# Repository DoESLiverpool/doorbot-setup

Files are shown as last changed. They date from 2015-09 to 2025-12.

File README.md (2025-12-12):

# Setup Doorbot

A set of scripts to set up a DoESLiverpool DoorBot.

## Structure

DoES Liverpool has three types of doorbot.  Most of the basics are shared between them all, and that is all contained within the `base-doorbot` role.  Other roles, such as the one running a web browser for doorbot1, are layered on top of that.

## Steps:

1. Install [Ansible](https://www.ansible.com/get-started) on your computer
1. Using the [Raspberry Pi Imager](https://www.raspberrypi.com/software/) install the latest 32-bit (I think John had trouble with the RFID code on the 64-bit) OS (needs updating for the headless ones, I used the desktop one as it was `doorbot2` that I was fixing, but I think we'd want "Raspberry Pi OS Lite"), and edit the settings to configure:
   * hostname
   * password
   * SSID
   * WiFi password
   * Enable the ssh service (use password authentication)
   (this didn't actually seem to set any of those options when I just tried it, and I had to do them manually with a screen and keyboard when the Pi first booted up)
1. Boot the Raspberry Pi with the micro-SD card, while plugged into a network via Ethernet
1. Find out the IP address of the Raspberry Pi
 * Use nmap (eg: `nmap -p 22 10.0.*.* --open`), router or monitor to find IP address of Pi once booted.
1. Copy your SSH credentials onto the Pi
  ```ssh-copy-id pi@<ip-address-of-the-pi>```
1. Edit the ```./hosts``` file so ansible knows which computer to configure.  Change the IP address in it to match the one you just found out.
1. Check you can run commands on the Pi using Ansible
   ```ansible <doorbotN> -i hosts -a "hostname" -u pi```
1. Create the hashed password file to use in a moment (if you don't already have it). At the prompt, provide the relevant password for the doorbot
   ```mkpasswd --method=sha-512 > protected_scripts/doorbot1-pwd.txt```
1. Change the SSH port and default password on the doorbot
   ```ansible-playbook ssh-config-doorbot1.yml -e pi_password=`cat protected_scripts/doorbot1-pwd.txt` -i hosts```
1. Populate `protected_scripts/id_ed25519` and `protected_scripts/id_ed25519.pub`, most likely by copying contents from an existing doorbot.
1. Update the Pi, using the correct playbook for the doorbot you're creating, e.g.
   ```ansible-playbook doorbot1.yml -i hosts```

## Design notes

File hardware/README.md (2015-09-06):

# Hardware

The non-software parts of a Doorbot.  

## pi-interface

KiCad project to define the PCB to interface from a Raspberry Pi to the SL030 RFID reader and a 12V door striker solenoid.  Takes power from a standard PC hard drive power connector.

Requires a number of additional parts libraries:

 * https://github.com/KiCad/kicad-library
 * http://www.smisioto.eu/elettronica/kicad

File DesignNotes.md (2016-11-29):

# DoES Liverpool Electronic Locking System

## Live System

There is a system currently live built on Raspberry Pi, this is not the final design but is enough to keep us going. More information on DoorBot page.

## Future Plans

This page contains some information about the electronic locking system for DoES Liverpool. This system is currently in the planning stages.

### Specifications

 * Computer can open door
  * Should fail locked
  * Can be opened by local RFID scan
  * Can be opened by a webpage which requires you to be on the local internet
  * Can be opened by administrators through other methods (SSH, doesbot, etc.)
 * RFID scan works offline (regularly downloads RFID details locally, or they're just stored there anyway)
 * Doorbell sends messages to IRC, twitter, etc. (and rings)
 * Failed RFID scan should cause a noise
 * Successful RFID scan should cause a noise, most likely the user's ringtone
 * For later:
  * Doorbot should show a message on the screen

Required materials might be:
 * Power for each unit with enough ampage to power all of the electronics
 * Control System
  * 2 x Raspberry Pi, provides network access, controls the electronics and hosts the USB RFID readers
  * 2 x Tikitag style RFID reader or [http://www.skpang.co.uk/catalog/hf-rfid-module-sl031-33v-uart-p-1066.html SL031]
 * Door System
  * Fail-locked Dorcas lock
  * Reed-switch to detect door open/closed state
 * Audio System
  * Speakers
  * Amplification
 * Door Bell

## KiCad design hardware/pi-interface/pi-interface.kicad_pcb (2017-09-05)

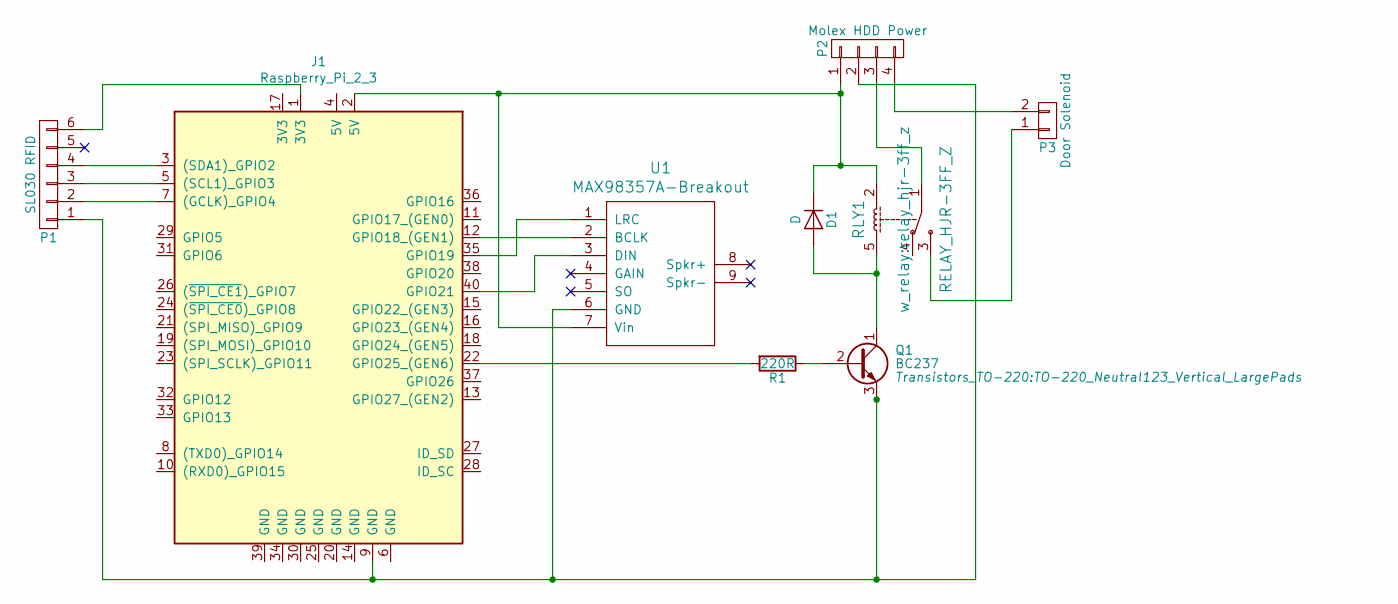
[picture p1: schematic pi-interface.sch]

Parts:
D1: D; Diode_DO-201AD_Horizontal_RM15
J1: Raspberry_Pi_2_3; Pin_Header_Straight_2x20
P1: SL030 RFID; Pin_Header_Angled_1x06
P2: Molex HDD Power; mstbva_2,5%2f4-g-5,08; Farnell Part 148086
P3: Door Solenoid; mstba_2,5%2f2-g-5,08; Farnell Part 2396251
Q1: BC237; TO-220_Neutral123_Vertical_LargePads
R1: 220R; Resistor_Horizontal_RM10mm
RLY1: RELAY_HJR-3FF_Z; relay_hjr-3ff_z; Farnell Part 2325631
U1: MAX98357A-Breakout; MAX98357-Breakout

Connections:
unnamed: D1.1 (K), J1.2 (5V), P2.1, RLY1.2, U1.7 (Vin)
unnamed: D1.2 (A), Q1.1 (C), RLY1.5
unnamed: J1.1 (3V3), P1.6
unnamed: J1.3 ((SDA1)_GPIO2), P1.4
unnamed: J1.5 ((SCL1)_GPIO3), P1.3
unnamed: J1.7 ((GCLK)_GPIO4), P1.2
unnamed: J1.9 (GND), P1.1, P2.2, Q1.3 (E), U1.6 (GND)
unnamed: J1.12 (GPIO18_(GEN1)), U1.2 (BCLK)
unnamed: J1.22 (GPIO25_(GEN6)), R1.2
unnamed: J1.35 (GPIO19), U1.1 (LRC)
unnamed: J1.40 (GPIO21), U1.3 (DIN)
unnamed: P2.3, RLY1.1
unnamed: P2.4, P3.2
unnamed: P3.1, RLY1.3
unnamed: Q1.2 (B), R1.1

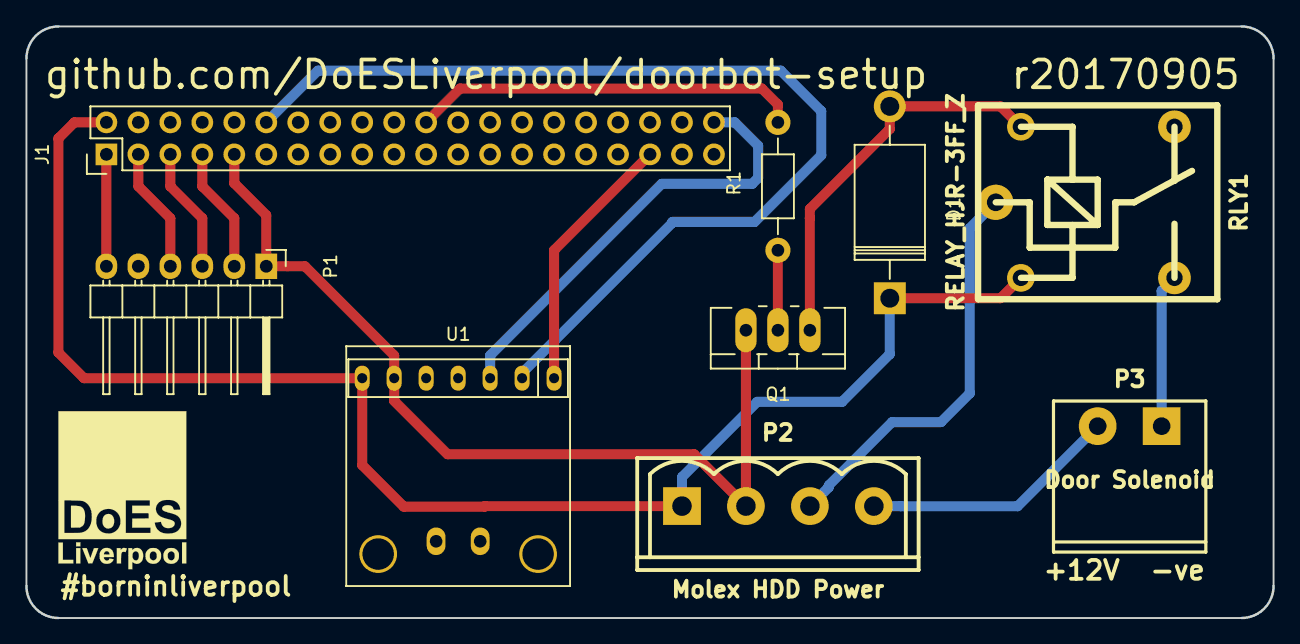
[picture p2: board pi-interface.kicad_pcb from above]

Board: 2 copper layers, 99.1 x 47.0 mm, 9 parts (0 on the bottom side), 15 nets.

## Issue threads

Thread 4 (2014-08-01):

Alternative web browser?

amcewen, 2014-08-01:
Happened upon http://www.raspberrypi.org/web-browser-beta/ which talks of a Pi-optimized web browser.  Might be worth a try as a replacement to Chrome, assuming it can do the same kiosk-mode sort of operation.

Closed 2015-06-14.

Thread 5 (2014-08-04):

Better mounting for Doorbot2 (kitchen/workshop)

amcewen, 2014-08-04:
If left to wobble around in its current cardboard box enclosure, Doorbot2 is prone to rebooting whenever there's a knock to the door, like when the door shuts :-)

We should find a proper mounting solution for the Pi and the little breakout board, so they can't move around.

johnmckerrell, 2019-05-13:
Closing this as we're no longer in Gostins!

Closed 2019-05-13.

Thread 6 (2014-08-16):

No documentation for hardware configuration

amcewen, 2014-08-16:
Would be useful to have a wiring diagram for how to connect the RFID reader, relay and door solenoid.

amcewen, 2015-09-07:
The schematic in https://github.com/DoESLiverpool/doorbot-setup/tree/master/hardware should be correct, and fairly soon we should have a finished PCB design to go with it (and to upgrade the existing doorbots)

amcewen, 2015-09-10:
With https://github.com/DoESLiverpool/doorbot-setup/commit/e998aa45418fa40833d94b1224c5a957882da672 we have the first version (or at least the first version to make into a PCB to try...).  @goatchurchprime is going to use it to test making PCBs on the Arcitype mill.

amcewen, 2017-08-16:
Latest PCB design sent off to DirtyPCBs.  We can update this if/when it works.

amcewen, 2017-09-05:
PCBs have arrived.  We need a few more parts to fully populate them, so they're on order from Farnell and should be with us tomorrow.

amcewen, 2017-10-04:
As can be seen in the comments on https://github.com/DoESLiverpool/somebody-should/issues/162 the PCB design works, apart from the soundcard (which might work, but hasn't been demonstrated to yet).  https://github.com/DoESLiverpool/somebody-should/issues/576 will cover the remaining testing work for this.

amcewen, 2017-11-06:
@helicalbytes soldered up another PCB over the weekend and the soundcard worked fine on that - it's now installed on the Kitchen doorbot.  So the remaining testing for this is done.

Closed 2017-11-06.

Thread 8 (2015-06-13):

No bitbucket credentials on the wiki

amcewen, 2015-06-13:
I can't find any way to add my bitbucket user (amcewen) to the DoES repository, so can't clone the config repository.

johnmckerrell, 2015-06-13:
Added you as an admin.

--
Sent from my mobile phone hence brevity and errors

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

DefProc, 2015-07-09:
And me too please (DefProc)

is this the de-facto place to sign-up to get access now then?

johnmckerrell, 2015-07-09:
It works ;-) Now added, we only get 5 users on the free plan, we're now at 3.

DefProc, 2015-07-09:
Is the update process documented anywhere?

What happens about new ringtones now?

amcewen, 2015-07-09:
See issues #2 and #11, and https://github.com/DoESLiverpool/somebody-should/issues/166 :-)

But basically, no.  My current process is:
 * ssh into doorbot1
 * tail logcards/scans.log
 * Add the new person to config.yaml **on my local machine, not the doorbot** and push that to bitbucket
 * On the doorbot, git pull to get the new config
 * Run reload-all-config to copy it across to doorbots 2 and 3

DefProc, 2015-09-23:
I've

DefProc, 2015-09-23:
I've made an rfid-keyboard to allow easier collection of the RFID UIDs: https://git.defproc.co.uk/DefProc/rfid-keyboard

So now, with the device plugged in as a USB keyboard, the process to add/search though a local clone of doorbot-setup can be done without ssh'ing to a doorbot for an ID number.

With the rfid-keyboard plugged in (and having set the keyboard map to QWERTY!):

 * Add the new person to config.yaml **on your local repo, not the doorbot** (scan the card where you need to input the UID)
 * commit & push that to bitbucket
 * On the doorbot, `cd logcards/doorbot-setup && git pull` to get the new config
 * Run `~/reload-all-config.sh` to copy it across to doorbots 2 and 3

Closed 2015-09-23.

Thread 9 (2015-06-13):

initial-local-setup.sh should unmount the SD card before running dd

amcewen, 2015-06-13:
The dd command to copy the Raspbian image over onto the SD card needs the SD card to be unmounted first.

The script doesn't currently check/perform this, and it should do.

amcewen, 2017-02-06:
No longer relevant after issue #18

Closed 2017-02-06.

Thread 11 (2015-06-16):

reload-all-config.sh script should pull from bitbucket

amcewen, 2015-06-16:
The canonical copy of the config.yaml lives in bitbucket.  However, so far we tend to update it on doorbot1 and just copy it across.

The reload-all-config.sh script should perform a git pull rather than copying things across.

DefProc, 2015-07-09:
Or would a post-update or post-receive hook allow auto updates when pushed, e.g.

 * run `git push`
 * hook ssh's to each doorbot in turn and runs `git pull`
 * success/failure info appears in the terminal during the push

Or would a separate script be better, e.g.

 * make commit and push to settings repo
 * run script to ssh to each doorbot and `git pull`

DefProc, 2015-07-30:
without having updated the `reload-local-config.sh` or `reload-all-config.sh` I have run 'ssh-copy-id' for doorbot 1&2, so the process to pull and reload stands at:

 * 'ssh doorbot1'
 * 'cd logcards/doorbot-config/'
 * 'git pull'
 * 'cd ../..'
 * './reload-local-config.sh'
 * 'sudo screen -x' (to check the config is fine)
 * './reload-all-config.sh'
 * 'exit'

DefProc, 2015-09-23:
I've made an rfid-keyboard to allow easier collection of the RFID UIDs: https://git.defproc.co.uk/DefProc/rfid-keyboard

So now, with the device plugged in as a USB keyboard, the process to add/search though a local clone of doorbot-setup can be done without ssh'ing to a doorbot for an ID number.

DefProc, 2015-09-23:
Ideally, the pull should happen from the user's local repo in a script. e.g:

 * git pull the `doorbots-config`
 * make local changes to `config.yaml`
 * test the yaml is valid ( #13 )
 * commit and push the config
 * (optionally) run a script locally to ssh across to each doorbot and have it pull the config and reload
 * (alternatively) leave the doorbots to auto-pull the most recent config ( #14 )

DefProc, 2016-06-09:
As a way of taking steps to improve the current process, I've written a pair of scripts that automate the `git pull`, checking if the yaml is valid and then either copying out to the other doorbots or restoring the previous known good configuration. These are derived from, and can be used in place of the older `reload-local-config` and `reload-all-config` scripts.

In the doorbots-config repo, there is now:

 * `config.yaml` has been moved to `_config.yaml` so the original is used as the current config on the actual doorbot
 * `update-rfids.sh` will (when run on the doorbot):
   * pull the remote repo
   * copy the new config into position
   * run `screen` for you to view the loading message from the new config
   * ask you if the loading message looked correct
   * either restore the original config
   * or copy the config to the other two doorbots
 * `ssh-update-rfids.sh` will (when run locally from inside DoES's network) ssh over to doorbot1 and run `update-rfids.sh` remotely

amcewen, 2017-02-06:
Have changed the title on this to reflect what the issue is now about.

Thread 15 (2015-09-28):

RFID keyboard inserts unnecessary 0s into output

amcewen, 2015-09-28:
Trying out the RFID keyboard mentioned in https://github.com/DoESLiverpool/doorbot-setup/issues/11#issuecomment-142584710 just now with @paulfurley's card, it ended up adding an extra 0 to the octet that was less than 0x10.

I'd have raised the issue on the keyboard's repo directly, but can't remember my login details for it.

DefProc, 2015-09-28:
Ah, most likely lines 81–85 in `arduino/src/sketch.ino`. I'll get on it.

DefProc, 2015-09-29:
Fixed

Closed 2015-09-29.

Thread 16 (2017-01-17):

Add a power switch to the custom PCB

amcewen, 2017-01-17:
We should add a reset button or power switch to the custom PCB to make it easier to power-cycle a non-responding doorbot (rather than having to pull the lead out of the PC power supply, as is the current option with doorbot1)

amcewen, 2017-08-14:
The newer Pi boards have a two-pin "RUN" connector, which can be used for a reset button.  It's not easy to pull onto the custom PCB, and it'd make more sense to wire it to a panel-mount button rather than one on the PCB (e.g. as suggested in https://github.com/DoESLiverpool/somebody-should/issues/451) so closing this as "won't fix".

DefProc, 2017-08-14:
The [UPS Pico](https://www.modmypi.com/raspberry-pi/breakout-boards-229/pi-modules/ups-pico) uses an (optional) pogo pin from the HAT to this hole location as a reset monitor. It's close enough to the 40-pin header that the connection has been reliable in my use.

Closed 2017-08-14.

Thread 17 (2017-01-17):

Add space for an I2S DAC for audio on the PCB

amcewen, 2017-01-17:
We could add one of [these I2S DAC boards with on-board amplifier](https://shop.pimoroni.com/products/adafruit-i2s-3w-class-d-amplifier-breakout-max98357a) to the doorbots in order to get better audio output (or remove the requirement for separate PC speakers)

See [my museuminabox work](https://github.com/museuminabox/brain/tree/master/Physical) for details of how to wire up the board (and check out the Ansible scripts elsewhere in that repo for details of how to configure the software side of the audio)

jamieisboss, 2017-05-19:
You dont really need the I2S i think unless you want some feature, you could just get some of the [very cheap (5V) PAM8403 boards](http://www.ebay.co.uk/itm/PAM8403-module-mini-digital-amplifier-board-2-3W-Class-D-amplifier-E69-/221435118465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) which will drive 2x 3w speakers, or build the PAM8403 into the pcb.

if you dont have an audio out you can use the [PWM DTO](https://github.com/raspberrypi/firmware/blob/master/boot/overlays/README#L1056) to get audio over the gpio and then amplify it

Closed 2017-08-16.

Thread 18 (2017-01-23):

Rework remote-setup.rb to use ansible

amcewen, 2017-01-23:
Given that https://github.com/DoESLiverpool/somebody-should/issues/426 shows up problems with the SD card size, it'd be good to move to Raspbian-lite rather than the full-fat Raspbian (given that that's a thing now :-)

If we're doing that, and working out what's needed to get X on doorbot1 (or working out if we don't need it as KWeb3 can possibly run direct to framebuffer) I'm considering switching over to ansible for the development (as I've already got bits of that lying around, e.g. https://github.com/mcqn/etherpad-in-a-box and https://github.com/museuminabox/brain/blob/master/INSTALL.md)

Raising this issue so I can create a branch referring to it, to make a start on it...

amcewen, 2017-01-23:
Have set up the Ansible scaffolding to make a start on this over on the branch https://github.com/DoESLiverpool/doorbot-setup/tree/feature/18-move-to-ansible

At present all it'll do is set the Pi's name to doorbot and install git and ruby.  There's a "base-doorbot" role which is where most of the setup steps will live, then the "install web browser, etc. for doorbot1" and "set up Kindle integration on doorbot3" can be layered on top (either as new roles, or just steps for the relevant doorbot in doorbot.yml)

I'm not 100% sure how to set it up, but it should be possible to set up groups of computers in the `hosts` file (I think) to allow us to then specify which doorbot we're building.
Need to move the rest of the things-that-need-installing into

amcewen, 2017-02-02:
The doorbot1 script is finished and pushed to the branch.  At present the "wait_for" step near the end has the Pi's IP address hard-coded, as I hadn't managed to get it working with the ansible variables (it should be something like "{{ ansible_host }}"

However, apart from that, doorbot1 is back up and running.

We need to add the config for doorbots 2 and 3 still.

Closed 2017-02-06.

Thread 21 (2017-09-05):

Holes for the Molex connector are a bit small

amcewen, 2017-09-05:
Doing a dry-run fit of the Molex power connector to the PCBs that were fabbed for #6 shows they don't quite fit through the holes.  We should make the holes in the PCB a tiny bit larger so next time we do an order (which might be a while, as we've got 24 of the current PCB to use up first :-)

As a workaround we should be fine to file down the pins on the Molex connector a touch.

Closed 2017-09-05.

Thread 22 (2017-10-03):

PCB fouls the USB/Ethernet jacks on the Pi

amcewen, 2017-10-03:
I wasn't paying enough attention to the hardware on the Pi that the PCB mounts onto and so designed it such that it fouls the higher components - the Ethernet jack and USB sockets on a Pi 2/3, and also the composite video connector on the Pi 1.

We should redesign it so that it doesn't foul, although as a workaround we could use Pi Zeros, or stackable headers.  (That's likely a reasonable first step, given we've got about 15 blank PCBs to use up first :-)

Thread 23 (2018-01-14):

High power traces on the PCB aren't thick enough

amcewen, 2018-01-14:
The kitchen doorbot has had two PCBs fail now with the tracks overheating and burning out.

We should make the traces which carry significant current (particularly the 12V traces connected to the solenoid) thicker.

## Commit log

2014-08-15 I suspect we should just add the i2c module to the ones loaded, rather than replace any already being loaded with i2c.
    I haven't tested this yet, mind.
2015-06-14 Now installs prerequisites and configures doesscreens if the config requires it. Fixes #3. Also uses KWeb3 as the browser in that case, which fixes #4
2015-09-06 A start on a PCB for the Raspberry Pi/RFID/door interface.
    [pi-interface.kicad_pcb, pi-interface.sch]
2015-09-07 Improved PCB, still needs checking against parts ordered
    [pi-interface.kicad_pcb, pi-interface.sch]
2015-09-10 First finished (fingers crossed) PCB design.
    [pi-interface.kicad_pcb, pi-interface.sch]
2017-01-23 Set up initial Ansible framework.
2017-08-16 I2S DAC added to PCB. Fixes #17
    Also added DoES Liverpool logo to silkscreen, and other mods for the first revision of the PCB sent to be manufactured.
    [pi-interface.kicad_pcb, pi-interface.sch]
2017-08-16 Panelized version and r20170815 Gerbers sent to production.
    [Doorbot-Panel.kicad_pcb]
2017-09-05 Enlarge holes for the Molex connector. Fixes #21
    [pi-interface.kicad_pcb, pi-interface.sch]
2017-09-05 Add Farnell part numbers for more of the components. Part of #6
    [pi-interface.sch]
2019-01-28 Switch the repo we use for doorbots-config and also add doorbots 4 & 5 to the ssh config
2025-12-11 Add I2C driver overlay so we don't get failures of the RFID app. Fixes #31
